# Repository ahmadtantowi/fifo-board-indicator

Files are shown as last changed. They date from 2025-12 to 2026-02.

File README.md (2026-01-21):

# FIFO Board Indicator

A FIFO box indicator board utilizing LED lamps to visually guide users on the order of box usage.

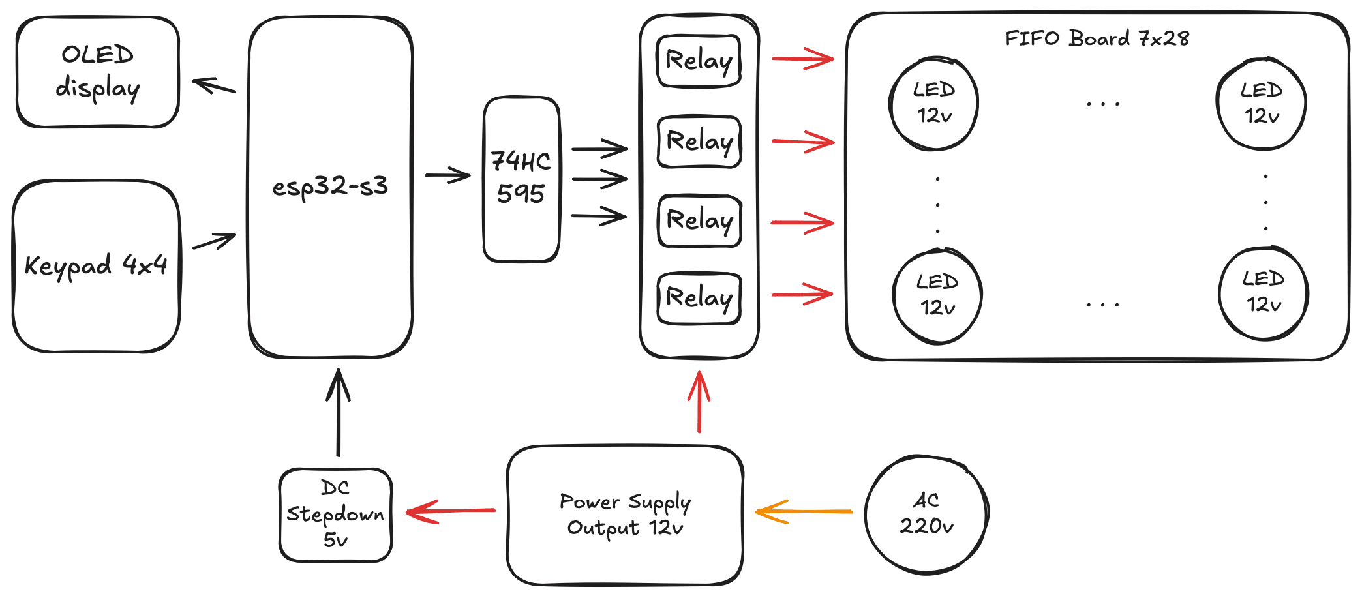
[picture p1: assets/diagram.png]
Diagram


## Wokwi Simulation (wokwi/diagram.json)

This project contains a Wokwi diagram file at `wokwi/diagram.json` plus a detailed guide at `wokwi/README.md`. Important: the `diagram.json` in this repository describes the simulated hardware wiring and components only — it does NOT include the firmware/sketch by default.

Visit [the Wokwi project](https://wokwi.com/projects/449662087423426561) to see the simulation in action.

Below is a screenshot of the Wokwi editor showing the loaded diagram.

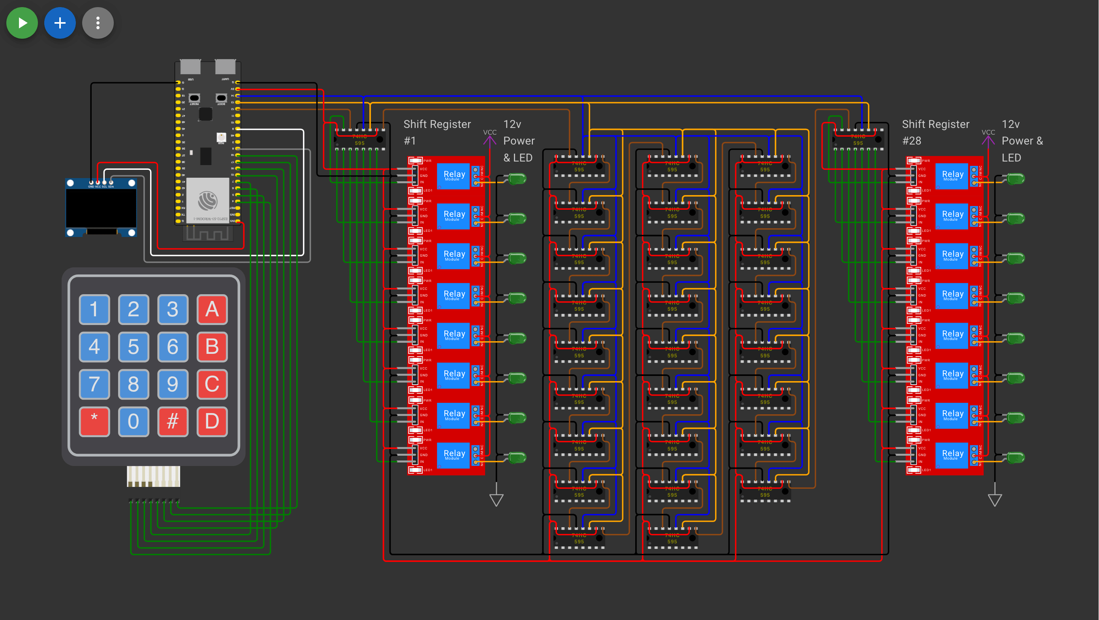
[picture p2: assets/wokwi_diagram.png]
Wokwi diagram screenshot


# Development Environment Setup

This guide explains how to set up and build the project using PlatformIO CLI and how to generate a `compile_commands.json` (compiledb) file so your editor's C/C++ language server (clangd / IntelliSense) can find Arduino and library headers (e.g. `Wire.h`, `Adafruit_GFX.h`, etc.).

This repository target platform: `esp32-s3-devkitc-1` with `framework = arduino`.

## Prerequisites

- Python 3.7+ (for PlatformIO CLI)
- Git (optional but recommended)
- A terminal (macOS / Linux / Windows PowerShell / Windows CMD)
- An editor (VS Code, Zed, or other). If you use VS Code with the PlatformIO extension, some intellisense steps below are optional.

## 1) Install PlatformIO CLI

See [PlatformIO Installation Guide](https://docs.platformio.org/en/latest/core/installation/index.html) and install the Shell Commands, so you can run `pio` from the terminal.

## 2) Ensure `platformio.ini` is configured

Open `platformio.ini` and make sure:
- `framework = arduino` is present.
- Required libraries are declared under `lib_deps` or installed via `pio lib install`.

A minimal example `platformio.ini` snippet (this project already includes one — if you modify it, ensure you add the libraries your code uses):

```/dev/null/platformio.ini#L1-40
[env:esp32-s3-devkitc-1]
platform = espressif32
board = esp32-s3-devkitc-1
framework = arduino
lib_deps =
  adafruit/Adafruit GFX Library
  adafruit/Adafruit SSD1306
  Keypad
```

If you prefer to install libraries manually (instead of relying on `lib_deps`), run:

```/dev/null/commands.sh#L1-6
pio lib install "Adafruit GFX Library"
pio lib install "Adafruit SSD1306"
pio lib install "Keypad"
```

Running `pio lib install` will add libraries to the project `.pio/libdeps` folder (or to the global library storage depending on your settings). Using `lib_deps` in `platformio.ini` lets PlatformIO fetch them automatically during `pio run`.

## 3) Build the project

From the project root (the directory containing `platformio.ini`):

```/dev/null/commands.sh#L1-4
# Build
pio run

# If you want verbose output (helps debugging missing headers)
pio run -v
```

Successful build output ends with a message like "Building . . . SUCCESS" and a `/.pio/build/<env>` folder with compiled objects.

Common build errors and how to fix them:
- `fatal error: Wire.h: No such file or directory`
  - Ensure `framework = arduino` is present in `platformio.ini`.
  - Ensure the proper board is set (so framework/toolchain selected is correct).
  - Make sure the Adafruit/Arduino libraries are installed (see `lib_deps` or run `pio lib install`).
  - Run `pio run -v` to see include paths and confirm where the compiler is looking.

- Missing `Adafruit_GFX.h` or `Keypad.h`:
  - Verify `lib_deps` contains those libraries OR install them manually via `pio lib install`.
  - After installing, run `pio run` again.

If things look stale, try cleaning and rebuilding:

```/dev/null/commands.sh#L1-6
pio run --target clean
rm -rf .pio/build .pio/libdeps .pio/.cache  # careful: removes PlatformIO caches
pio run
```

## 4) Generate `compile_commands.json` for editor intellisense (Optional, but recommended)

Many language servers (clangd, ccls) and editors accept a `compile_commands.json` database that contains the compile flags and include paths for each translation unit. PlatformIO can generate it for you.

```/dev/null/commands.sh#L1-6
# From project root
pio run --target compiledb
# This produces a compile_commands.json (or a json in .pio) in the project root.
```

What this does:
- Produces `compile_commands.json` that tools like clangd use to get the exact include paths and flags used by PlatformIO.
- This resolves editor diagnostics such as "Wire.h not found" and other header resolution issues.

Editor-specific notes:
- VS Code with the official PlatformIO extension: compiledb is typically not required because the extension already configures IntelliSense. Still, generating `compile_commands.json` is harmless and can help external tools.
- Zed or other editors using `clangd`: after generating `compile_commands.json`, restart your editor or the language server so it picks the file up and re-indexes the project.

## 5) Editor integration / clangd troubleshooting (Zed, others)

If your editor still shows `Wire.h` or other "file not found" diagnostics after generating the compiledb:

1. Confirm `compile_commands.json` exists in the project root.
2. Restart the editor / language server (e.g., reload window).
3. Confirm the language server is configured to look for `compile_commands.json` in the project root. clangd normally auto-detects it.
4. If your editor has a caching layer, clear or re-index the project.

## 6) Extra PlatformIO commands that help diagnose issues

```/dev/null/commands.sh#L1-12
# Show project environments and targets
pio project inspect

# Show installed libs
pio lib list

# Force update of platform and libraries
pio update

# Remove and reinstall libs
pio lib uninstall <LIBNAME>
pio lib install <LIBNAME>
```

## 7) Example quick checklist to get to a successful `pio run`

1. Ensure Python is installed and `pio` works:
   ```/dev/null/commands.sh#L1-4
   python3 -m pip install -U platformio
   pio --version
   ```
2. Confirm `platformio.ini` includes `framework = arduino` and (optionally) `lib_deps`.
3. Install libraries if needed:
   ```/dev/null/commands.sh#L1-3
   pio lib install "Adafruit GFX Library"
   pio lib install "Adafruit SSD1306"
   pio lib install "Keypad"
   ```
4. Build:
   ```/dev/null/commands.sh#L1-3
   pio run
   ```
5. If editor diagnostics show missing headers, generate compiledb:
   ```/dev/null/commands.sh#L1-2
   pio run --target compiledb
   # Restart editor / language server
   ```

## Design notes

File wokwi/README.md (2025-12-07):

# Wokwi Simulation: `diagram.json`

This folder contains a Wokwi project description file: `diagram.json`.  
`diagram.json` is the Wokwi diagram / project file that describes the virtual breadboard, components, wiring, and the MCU used in the simulation. Use it to open and inspect the circuit in the Wokwi web simulator.

This README explains:
- what `diagram.json` is,
- how to open it in Wokwi,
- how to run the simulation and inspect common outputs (serial, pins),
- troubleshooting tips.

---

## What is `diagram.json`?

- `diagram.json` is a Wokwi project file (JSON format). It encodes:
  - the microcontroller/avatar (e.g., an ESP32, AVR, or other supported board),
  - attached parts (shift registers, OLED, keypad, LEDs, resistors, etc.),
  - wiring between parts,
  - optional references to source files.
- When loaded into the Wokwi editor, it reconstructs the schematic/diagram so you can simulate behavior — but note the important caveat below.

---

## Important: this diagram does NOT include firmware/program

- The `diagram.json` in this repository describes only the circuit and wiring. It does NOT contain the compiled firmware nor an embedded sketch by default.
- To run code in Wokwi you must add or paste the Arduino sketch/source code in the Wokwi editor after loading the diagram (instructions below).

---

## How to open `diagram.json` on Wokwi

There are several ways to open the diagram in Wokwi. Choose whichever is most convenient:

Option A — Drag & Drop (quick)
1. Open your browser and go to: https://wokwi.com
2. Click the “Open Editor” / “Start simulation” area (or the Projects link).
3. Drag `diagram.json` from your file system into the Wokwi editor window.
4. Wokwi will parse the JSON and load the project.

Option B — Import / Upload
1. Go to https://wokwi.com and open the online editor.
2. In the editor, find the menu (often top-right) with “Import project” / “Open” / “Upload”.
3. Choose to upload a file and select `diagram.json`.
4. The project will load.

Option C — Paste JSON (if file > copy)
1. Open the Wokwi editor.
2. If there is an “Import JSON” or “Open from JSON” option, open it and paste the contents of `diagram.json`.
3. Load the project.

Option D — Host the JSON and open by URL (advanced)
- If you host the `diagram.json` at a raw URL (GitHub gist/raw file, raw file serving), Wokwi may allow importing by URL. Use the editor's import-from-URL option if available.

---

## Adding code / Running the simulation

1. After loading the diagram, open the **Code** or **Files** panel in the Wokwi editor.
2. Create a new Arduino sketch file (for example `main.cpp`) or paste your existing sketch code into the editor.
3. Ensure your sketch includes `Serial.begin(...)` if you expect serial output, and verify that pin numbers/constants in the code match the wiring in the diagram.
4. Click the Run / Play button to compile and start the simulation. Use the Serial Monitor panel to view serial output.

Notes on importing repository code:
- To test the code from this repository, copy the relevant source files into Wokwi's editor or export a zip of the repository and import it if Wokwi supports zips for your project.
- Alternatively, paste the essential parts of the sketch (setup/loop and pin definitions) into the Wokwi code editor.

---

## Running the simulation (behavior & interaction)

1. Press the Run / Play button in the Wokwi editor.
2. To view serial output (Serial Monitor), open the console/serial panel (usually bottom-right or via a "Serial" tab).
3. Interact with simulated inputs (e.g., press virtual keypad buttons, toggle switches) with the mouse.
4. The display (OLED) and other components will update in real time per the simulated firmware behavior.

---

## Tips & Troubleshooting

- If the project fails to load:
  - Ensure the JSON is valid (no truncated content).
  - Try opening the file with a text editor and verify it begins with `{` and contains Wokwi components.
- If components don't behave as expected:
  - Confirm that the simulated MCU type matches your intended board (ESP32 vs. AVR).
  - Check wiring/pin numbers — simulated pins must match code.
- Serial output not visible:
  - Ensure your sketch calls `Serial.begin(...)` and prints to the correct port.
  - Open the Wokwi Serial Monitor panel after starting the simulation.
- If Wokwi cannot run the project due to unsupported parts or features:
  - Replace unsupported components with functional equivalents available in the Wokwi parts library.
- If you want to iterate quickly:
  - Edit code in Wokwi and use the Run button to test changes without leaving the browser.
  - For larger codebases, continue editing locally and upload or paste the updated sketch into Wokwi.

---

## Exporting and sharing

- After loading or editing a project in Wokwi you can:
  - Export the project (zip) to use with PlatformIO locally.
  - Share a link (if using Wokwi’s publish/share features) so others can open the same simulation.

---

## Where to go next

- Open `diagram.json` in Wokwi and add/paste the sketch code into the Code panel, then run the simulation to observe:
  - how the keypad input changes displayed messages,
  - how shift-register outputs (relays/LEDs) are simulated,
  - serial logs from the firmware.
- If you'd like, I can help prepare a minimal, Wokwi-ready example sketch you can paste into the editor — tell me which MCU and which pins you want the sketch to use.

--- 

If anything in the editor looks off after loading the JSON, paste the exact Wokwi error or describe what does not match the expected hardware behavior and I’ll help you resolve it.

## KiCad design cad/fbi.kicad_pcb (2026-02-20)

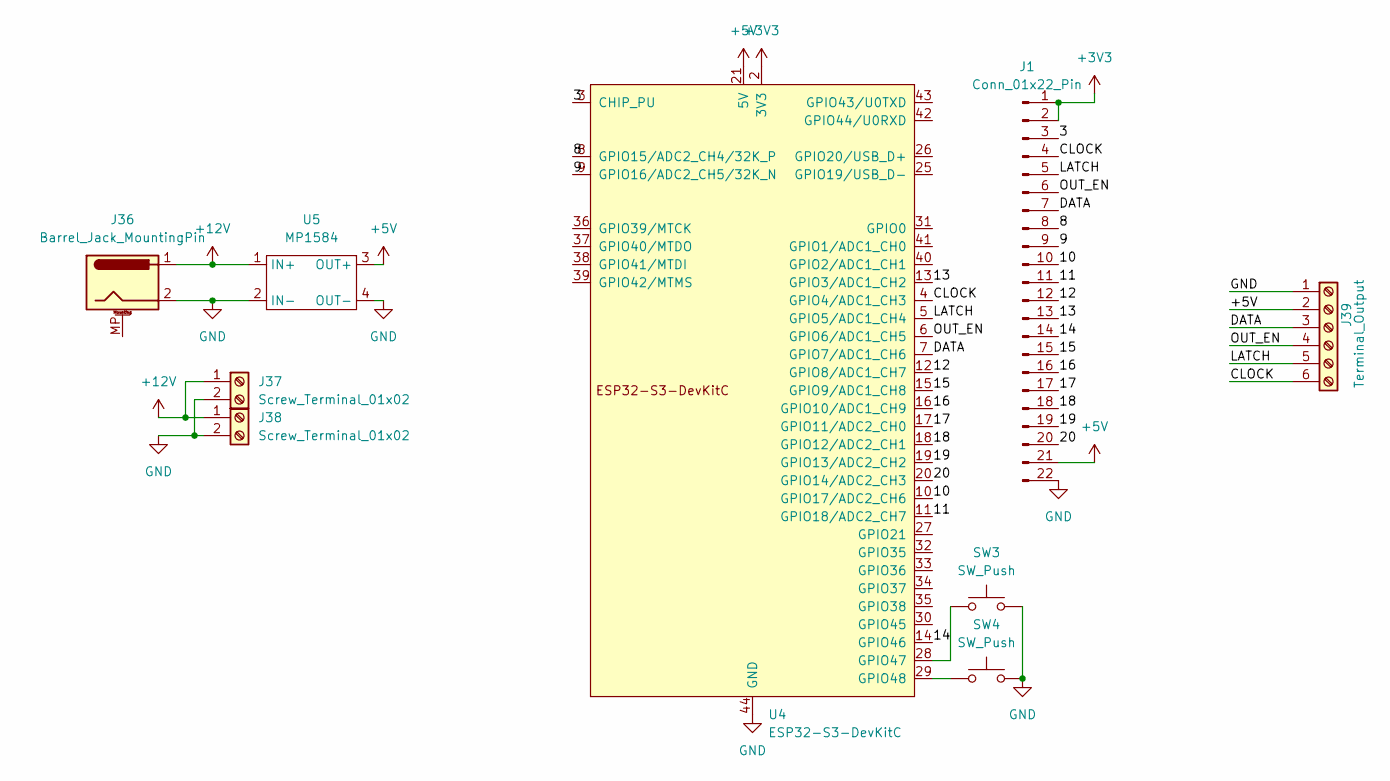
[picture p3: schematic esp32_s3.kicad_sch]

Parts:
J1: Conn_01x22_Pin; PinSocket_1x22_P2.54mm_Vertical
J36: Barrel_Jack_MountingPin; BarrelJack_Horizontal
J37, J38: Screw_Terminal_01x02; TerminalBlock_MaiXu_MX126-5.0-02P_1x02_P5.00mm
J39: Terminal_Output; TerminalBlock_Xinya_XY308-2.54-6P_1x06_P2.54mm_Horizontal
SW3, SW4: SW_Push; SW_PUSH_6mm
U4: ESP32-S3-DevKitC
U5: MP1584; MP1584-Module_B22.1x16.8mm

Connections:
+3V3: J1.1, J1.2, U4.1 (3V3), U4.2 (3V3)
+5V: J1.21, J39.2, U4.21 (5V), U5.3 (OUT+); also elsewhere on the board
+12V: J36.1, J37.1, J38.1, U5.1 (IN+)
/ESP32-S3/3: J1.3, U4.3 (CHIP_PU)
/ESP32-S3/8: J1.8, U4.8 (GPIO15/ADC2_CH4/32K_P)
/ESP32-S3/9: J1.9, U4.9 (GPIO16/ADC2_CH5/32K_N)
/ESP32-S3/10: J1.10, U4.10 (GPIO17/ADC2_CH6)
/ESP32-S3/11: J1.11, U4.11 (GPIO18/ADC2_CH7)
/ESP32-S3/12: J1.12, U4.12 (GPIO8/ADC1_CH7)
/ESP32-S3/13: J1.13, U4.13 (GPIO3/ADC1_CH2)
/ESP32-S3/14: J1.14, U4.14 (GPIO46)
/ESP32-S3/15: J1.15, U4.15 (GPIO9/ADC1_CH8)
/ESP32-S3/16: J1.16, U4.16 (GPIO10/ADC1_CH9)
/ESP32-S3/17: J1.17, U4.17 (GPIO11/ADC2_CH0)
/ESP32-S3/18: J1.18, U4.18 (GPIO12/ADC2_CH1)
/ESP32-S3/19: J1.19, U4.19 (GPIO13/ADC2_CH2)
/ESP32-S3/20: J1.20, U4.20 (GPIO14/ADC2_CH3)
/ESP32-S3/CLOCK: J1.4, J39.6, U4.4 (GPIO4/ADC1_CH3)
/ESP32-S3/DATA: J1.7, J39.3, U4.7 (GPIO7/ADC1_CH6)
/ESP32-S3/LATCH: J1.5, J39.5, U4.5 (GPIO5/ADC1_CH4)
/ESP32-S3/OUT_EN: J1.6, J39.4, U4.6 (GPIO6/ADC1_CH5)
GND: J1.22, J36.2, J37.2, J38.2, J39.1, SW3.2, SW4.2, U4.22 (GND), U4.23 (GND), U4.24 (GND), U4.44 (GND), U5.2 (IN-), U5.4 (OUT-); also elsewhere on the board
unnamed: SW3.1, U4.28 (GPIO47)
unnamed: SW4.1, U4.29 (GPIO48)

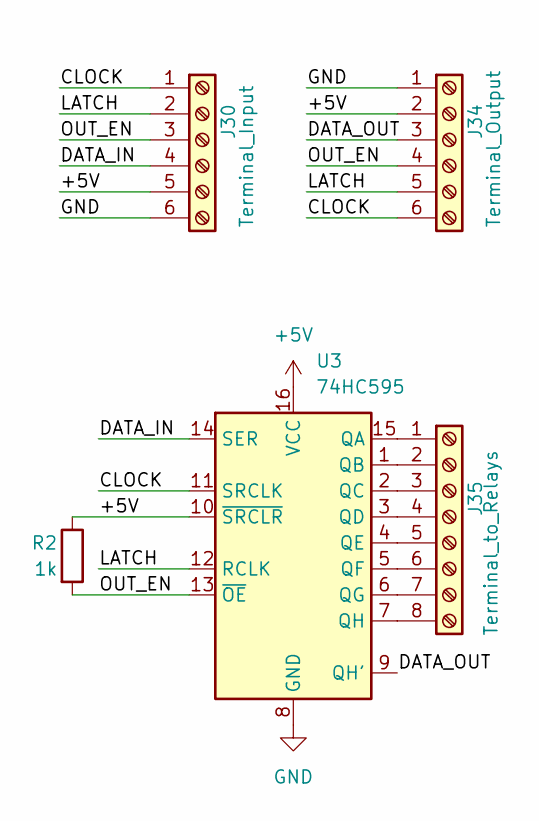
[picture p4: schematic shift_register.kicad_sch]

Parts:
J30: Terminal_Input; TerminalBlock_Xinya_XY308-2.54-6P_1x06_P2.54mm_Horizontal
J34: Terminal_Output; TerminalBlock_Xinya_XY308-2.54-6P_1x06_P2.54mm_Horizontal
J35: Terminal_to_Relays; TerminalBlock_MaiXu_MX126-5.0-08P_1x08_P5.00mm
R2: 1k; R_Axial_DIN0204_L3.6mm_D1.6mm_P7.62mm_Horizontal
U3: 74HC595; DIP-16_W7.62mm_LongPads

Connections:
+5V: J30.5, J34.2, R2.1, U3.10 (~SRCLR), U3.16 (VCC); also elsewhere on the board
/Shift Register/CLOCK: J30.1, J34.6, U3.11 (SRCLK)
/Shift Register/DATA_IN: J30.4, U3.14 (SER)
/Shift Register/DATA_OUT: J34.3, U3.9 (QH')
/Shift Register/LATCH: J30.2, J34.5, U3.12 (RCLK)
/Shift Register/OUT_EN: J30.3, J34.4, R2.2, U3.13 (~OE)
GND: J30.6, J34.1, U3.8 (GND); also elsewhere on the board
unnamed: J35.1, U3.15 (QA)
unnamed: J35.2, U3.1 (QB)
unnamed: J35.3, U3.2 (QC)
unnamed: J35.4, U3.3 (QD)
unnamed: J35.5, U3.4 (QE)
unnamed: J35.6, U3.5 (QF)
unnamed: J35.7, U3.6 (QG)
unnamed: J35.8, U3.7 (QH)

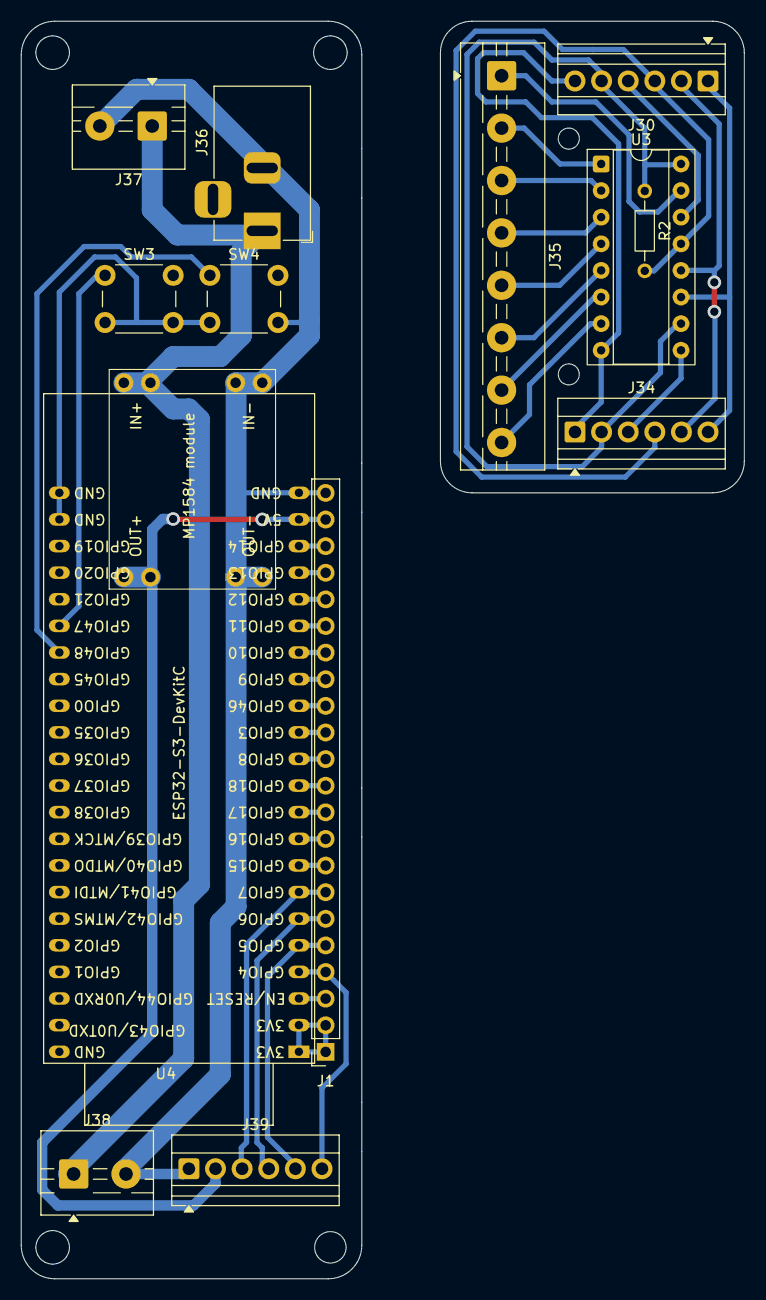
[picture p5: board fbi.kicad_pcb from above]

Board: 2 copper layers, 69.0 x 120.0 mm, 14 parts (0 on the bottom side), 37 nets.

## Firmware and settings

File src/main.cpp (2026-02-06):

/*
  ESP32-S3 + 74HC595 Chain Control (28 Shift Registers, 224 Relays)
  + Keypad Control (A,B,C,D Features added)
  + OLED Status Display
*/

#include <Wire.h>
#include <Adafruit_GFX.h>
#include <Adafruit_SSD1306.h>
#include <Keypad.h>

// --- Config: Buttons ---
#define BUTTON_A 28
#define BUTTON_B 29

// --- Config: Shift Registers ---
#define CLOCK_PIN 4
#define LATCH_PIN 5
#define OE_PIN    6
#define DATA_PIN  7
#define NUM_SHIFT_REGISTERS 28
#define NUM_LEDS (NUM_SHIFT_REGISTERS * 8)

// --- Config: OLED Display ---
#define SCREEN_WIDTH 128
#define SCREEN_HEIGHT 64
#define OLED_RESET    -1
#define SCREEN_ADDRESS 0x3C
#define OLED_SDA 8
#define OLED_SCL 9

Adafruit_SSD1306 display(SCREEN_WIDTH, SCREEN_HEIGHT, &Wire, OLED_RESET);

// --- Config: Keypad ---
const byte ROWS = 4;
const byte COLS = 4;
char keys[ROWS][COLS] = {
  {'1','2','3','A'},
  {'4','5','6','B'},
  {'7','8','9','C'},
  {'*','0','#','D'}
};
byte rowPins[ROWS] = {4, 5, 6, 7};
byte colPins[COLS] = {15, 16, 17, 18};

Keypad keypad = Keypad( makeKeymap(keys), rowPins, colPins, ROWS, COLS );

// --- Global Variables ---
byte relayStates[NUM_SHIFT_REGISTERS];
String inputBuffer = "";

// Forward declarations for functions
void handleKeypress(char key);
void setAllRelays(bool state);
void runSequence();
void flashAllRelays();
void sweepShiftRegisters();
void toggleRelay(int relayId);
void setRelay(int ledId, bool state);
void updateShiftRegisters();
void updateStatusScreen();
void updateDisplay(String line1, String line2);

void setup() {
  Serial.begin(115200);
  pinMode(BUTTON_A, INPUT_PULLUP);
  pinMode(BUTTON_B, INPUT_PULLUP);

  // 1. Initialize Shift Register Pins
  pinMode(LATCH_PIN, OUTPUT);
  pinMode(CLOCK_PIN, OUTPUT);
  pinMode(DATA_PIN, OUTPUT);
  pinMode(OE_PIN, OUTPUT);
  digitalWrite(OE_PIN, HIGH); // Disable outputs at startup

  // Clear all LEDs initially
  setAllRelays(false);

  // 2. Initialize OLED
  Wire.begin(OLED_SDA, OLED_SCL);
  if(!display.begin(SSD1306_SWITCHCAPVCC, SCREEN_ADDRESS)) {
    Serial.println(F("SSD1306 allocation failed"));
    for(;;);
  }
  display.clearDisplay();
  display.setTextColor(SSD1306_WHITE);

  // Show Startup Screen
  updateDisplay("Ready", "Type ID#");

  // Enable outputs after startup init completes
  digitalWrite(OE_PIN, LOW);

  sweepShiftRegisters(); // Run a register sweep once after flash
}

void loop() {
  char key = keypad.getKey();

  if (key) {
    handleKeypress(key);
  }
  if (digitalRead(BUTTON_A) == LOW) {
      setAllRelays(true);
      delay(1000);
      setAllRelays(false);
  }
}

// --- Logic: Keypad Handling ---
void handleKeypress(char key) {
  // If user types a number (0-9)
  if (key >= '0' && key <= '9') {
    if (inputBuffer.length() < 3) {
      inputBuffer += key;
    }
    updateStatusScreen();
  }
  // If user presses '*' -> Clear Input
  else if (key == '*') {
    inputBuffer = "";
    updateDisplay("Cleared", "Type ID#");
  }
  // If user presses '#' -> Toggle the specific Relay ID
  else if (key == '#') {
    if (inputBuffer.length() > 0) {
      int id = inputBuffer.toInt();
      toggleRelay(id);
      inputBuffer = "";
    }
  }
  // --- NEW FEATURES ---
  else if (key == 'A') {
    inputBuffer = "";
    updateDisplay("Action:", "All OFF");
    setAllRelays(false); // Turn all OFF
  }
  else if (key == 'B') {
    inputBuffer = "";
    updateDisplay("Action:", "Sequence...");
    runSequence(); // Run sequential chaser
  }
  else if (key == 'C') {
    inputBuffer = "";
    updateDisplay("Action:", "Flashing!");
    flashAllRelays(); // Flash 3 times
  }
  else if (key == 'D') {
    inputBuffer = "";
    updateDisplay("Action:", "All ON");
    setAllRelays(true); // Turn all ON
  }
}

// --- Logic: Special Functions ---

// Helper to set ALL relays ON or OFF at once
void setAllRelays(bool state) {
  byte fillValue = state ? 0xFF : 0x00; // 0xFF is 11111111, 0x00 is 00000000
  for (int i = 0; i < NUM_SHIFT_REGISTERS; i++) {
    relayStates[i] = fillValue;
  }
  updateShiftRegisters();
}

// Keypad B: Run relays sequentially (Chaser effect)
void runSequence() {
  // Ensure everything is off first
  setAllRelays(false);

  for (int i = 0; i < NUM_LEDS; i++) {
    // Check if user wants to abort sequence by pressing '*'
    char key = keypad.getKey();
    if (key != NO_KEY && key == '*') {
      updateDisplay("Stopped", "Ready");
      setAllRelays(false);
      return;
    }

    setRelay(i, true);
    updateShiftRegisters();
    delay(30); // Speed of the sequence (adjust as needed)
    setRelay(i, false); // Turn it off to create a "moving dot" effect
    // Note: Remove the line above if you want them to "fill up" instead of "chase"
  }
  // Ensure last one is off
  updateShiftRegisters();
  updateDisplay("Done", "Ready");
}

// Keypad C: Flash all relays 3 times
void flashAllRelays() {
  for(int k=0; k<3; k++) {
    setAllRelays(true);
    delay(200);
    setAllRelays(false);
    delay(200);
  }
  updateDisplay("Done", "Ready");
}

void sweepShiftRegisters() {
  setAllRelays(false);
  for (int bit = 0; bit < 8; bit++) {
    for (int reg = 0; reg < NUM_SHIFT_REGISTERS; reg++) {
      relayStates[reg] |= (1 << bit);
    }
    updateShiftRegisters();
    delay(75);
    for (int reg = 0; reg < NUM_SHIFT_REGISTERS; reg++) {
      relayStates[reg] &= ~(1 << bit);
    }
  }
  updateShiftRegisters();
}

// --- Logic: Relay Control ---

// Toggle a specific relay ID
void toggleRelay(int relayId) {
  if (relayId < 0 || relayId >= NUM_LEDS) {
    updateDisplay("Error", "Invalid ID");
    return;
  }

  int registerIndex = relayId / 8;
  int bitIndex = relayId % 8;

  bool isOne = (relayStates[registerIndex] & (1 << bitIndex));

  setRelay(relayId, !isOne);
  updateShiftRegisters();

  String statusMsg = "Relay " + String(relayId);
  String stateMsg = !isOne ? "ON" : "OFF";
  updateDisplay(statusMsg, stateMsg);
}

// Basic set relay function (updates array only)
void setRelay(int ledId, bool state) {
  if (ledId < 0 || ledId >= NUM_LEDS) return;
  int registerIndex = ledId / 8;
  int bitIndex = ledId % 8;

  if (state) {
    relayStates[registerIndex] |= (1 << bitIndex);
  } else {
    relayStates[registerIndex] &= ~(1 << bitIndex);
  }
}

// Push data to chips
void updateShiftRegisters() {
  digitalWrite(LATCH_PIN, LOW);
  for (int i = NUM_SHIFT_REGISTERS - 1; i >= 0; i--) {
    shiftOut(DATA_PIN, CLOCK_PIN, MSBFIRST, relayStates[i]);
  }
  digitalWrite(LATCH_PIN, HIGH);
}

// --- Logic: Display Helper ---

void updateStatusScreen() {
  int id = inputBuffer.toInt();
  String top = "Target: " + inputBuffer;

  String bottom = "";
  if (id >= 0 && id < NUM_LEDS) {
    int registerIndex = id / 8;
    int bitIndex = id % 8;
    bool isOn = (relayStates[registerIndex] & (1 << bitIndex));
    bottom = "Curr: " + String(isOn ? "ON" : "OFF");
  } else {
    bottom = "Inv Range";
  }

  updateDisplay(top, bottom);
}

void updateDisplay(String line1, String line2) {
  display.clearDisplay();
  display.setTextSize(2);
  display.setCursor(0, 0);
  display.println(line1);
  display.setCursor(0, 32);
  display.println(line2);
  display.display();
}

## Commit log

2025-12-07 Add Wokwi schematic with 224 relays and ESP32
2025-12-07 Add Wokwi preview and update diagram JSON
    Add screenshot and save diagram JSON to assets for quick access.
    Simplify and reorganize wokwi/diagram.json: rename parts (esp→esp1,
    sr→sr1), remove many relay modules, add OLED, keypad, LEDs, VCC/GND,
    update connections and metadata.
2026-01-15 Enable OE pin and add shift register sweep
    Use pin 11 as OE, set it to OUTPUT and drive HIGH at startup to keep
    outputs off during initialization, then drive LOW once setup completes.
    Implement sweepShiftRegisters() to pulse each bit across all registers
    as a quick visual test and call it once after startup.
2026-01-16 Expand .gitignore for KiCad and temp files
2026-02-06 Cad design (#1)
    * Initialized schematic and pcb design with esp-32 s3 and 74hc595 x28
    * Fix incorrect shift register output connection
    * Add symbol and footprint lib for MP1584 module
    * Ignore .DS_Store file
    * Add power source
    * Add schema title, button and remove pin header
    * Place components on PCB
    * Wiring the 12v
    * Update MP1584 module
    * Reposition all components
    * Change button pin
    * WIP wiring
    * Fixing the grid
    * Try separate shift register module
    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
    [esp32_s3.kicad_sch, fbi.kicad_pcb, fbi.kicad_sch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]
2026-02-06 Match GPIO pin with Schema design
2026-02-20 Separate pcb for print
    [fbi.kicad_pcb, print1.kicad_pcb, print2.kicad_pcb]
